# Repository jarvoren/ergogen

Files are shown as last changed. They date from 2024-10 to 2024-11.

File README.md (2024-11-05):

Monster keybord.
Pcb mounted switches and overall very basic version of the keyboard.
Ergogen used in the build in repo. Actually had a lot of problems with this one.

Will improve when i regain the will to live after this one.

Zmk firmware : 
https://github.com/jarvoren/zmk-config-monster

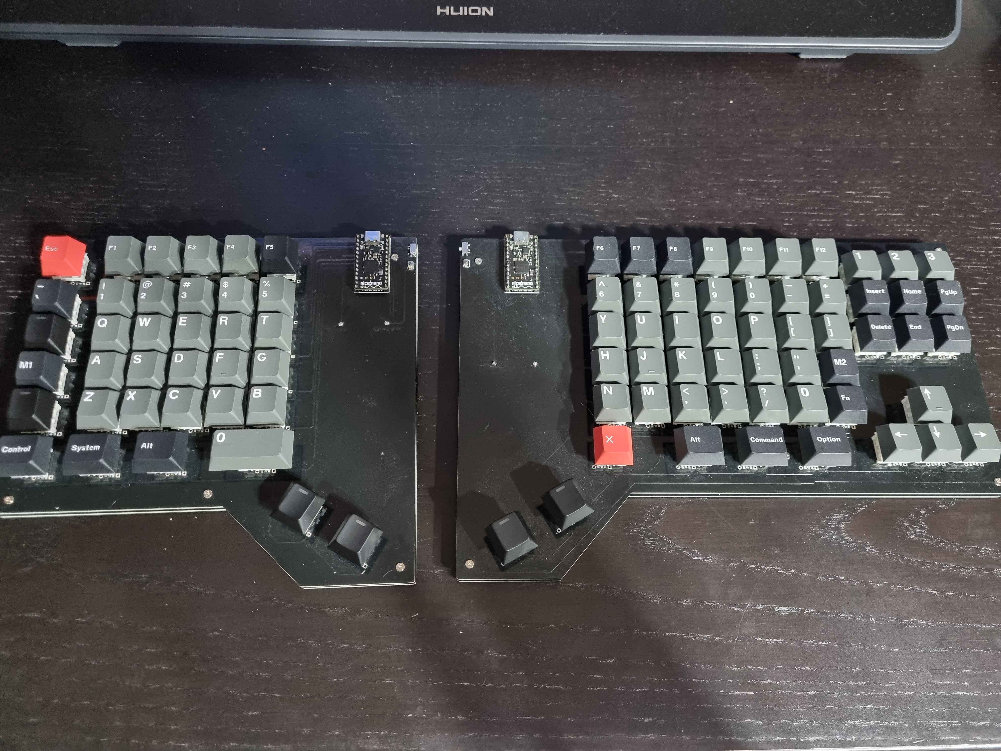
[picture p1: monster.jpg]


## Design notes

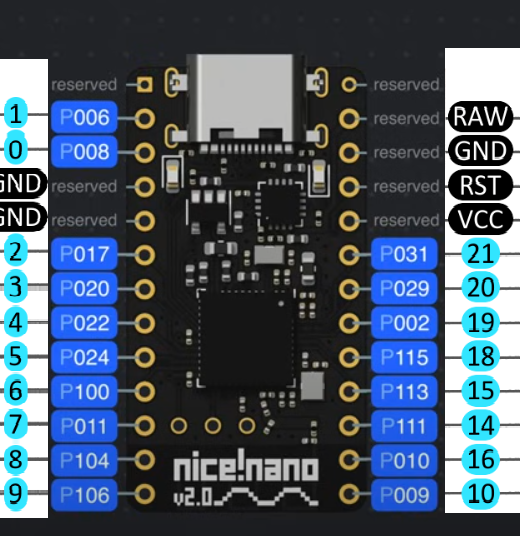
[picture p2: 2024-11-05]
configs/nicenano pinouts.png

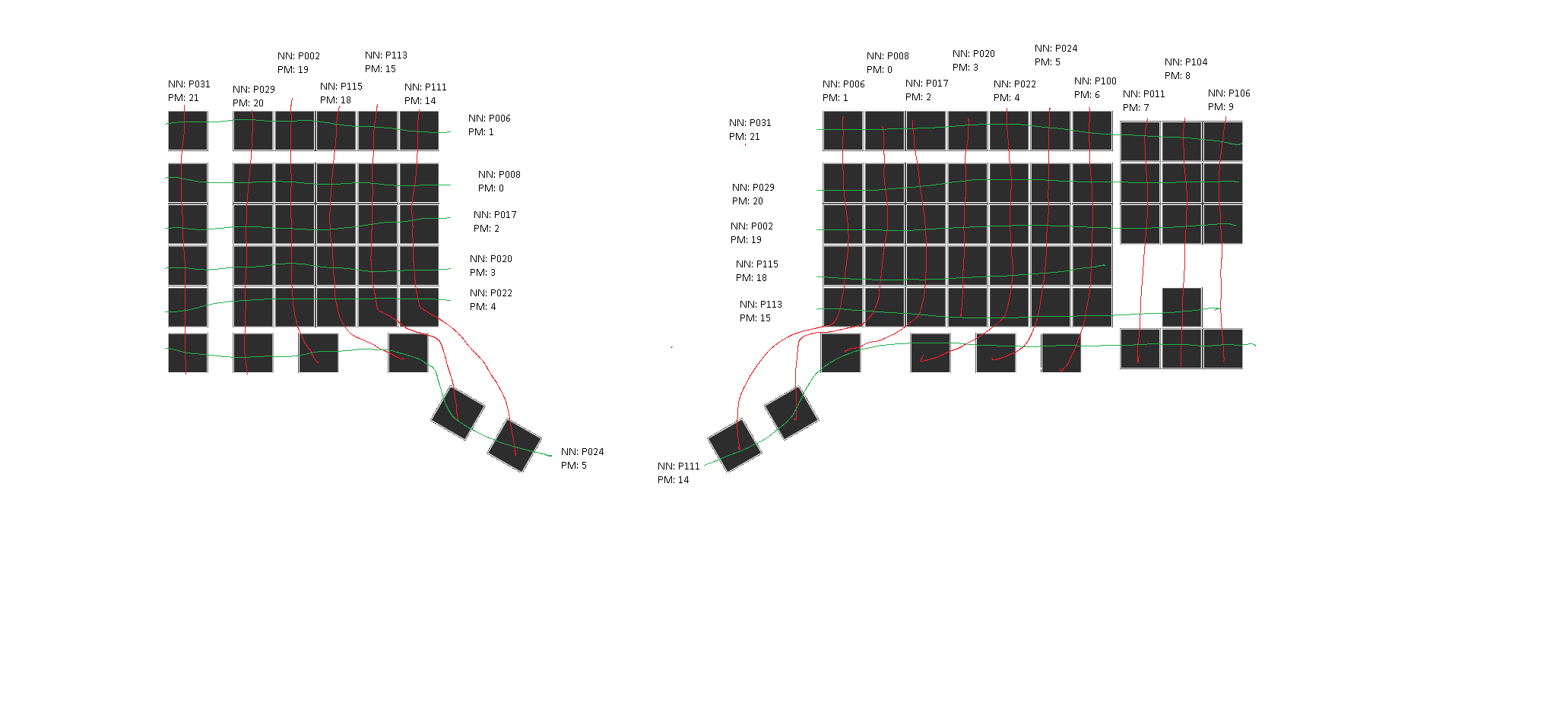
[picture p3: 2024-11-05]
configs/nicenano matrix mappings.png

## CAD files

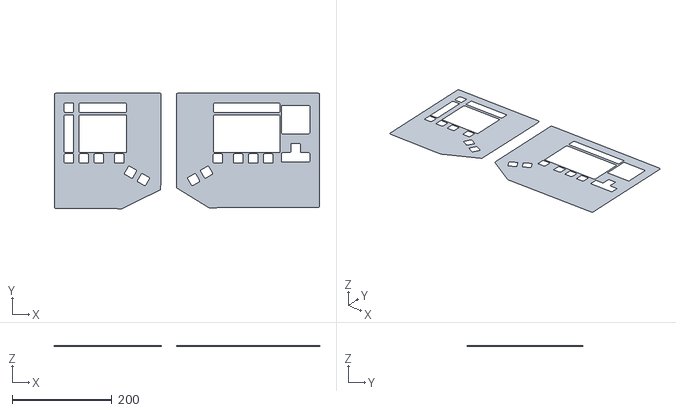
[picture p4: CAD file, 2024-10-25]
output/cases/bottom.stl
532.0 x 232.0 x 1.00

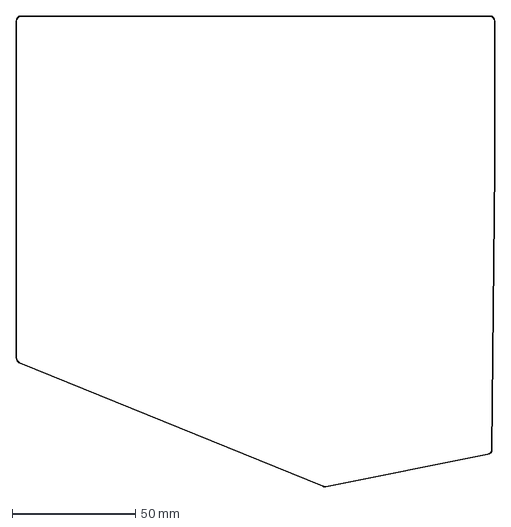
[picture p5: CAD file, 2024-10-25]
output/outlines/pcbplanleft.dxf
194.0 x 191.0 mm

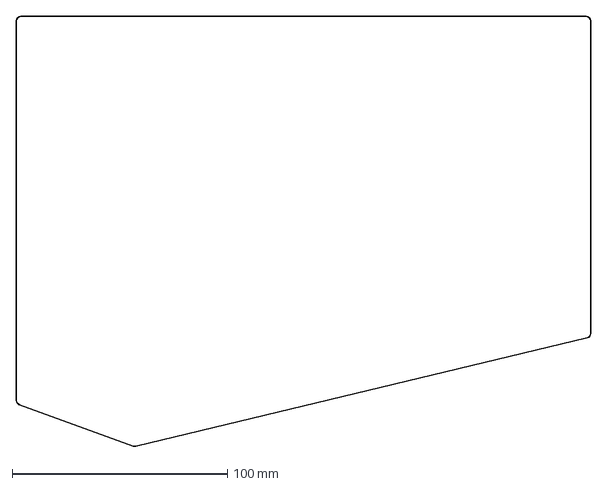
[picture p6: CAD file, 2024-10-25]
output/outlines/pcbplanright.dxf
267.0 x 200.0 mm

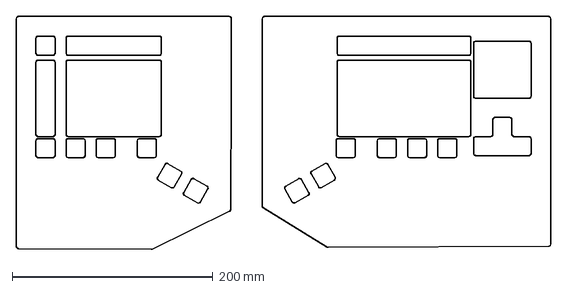
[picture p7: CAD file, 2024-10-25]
output/outlines/raw.dxf
532.0 x 232.0 mm

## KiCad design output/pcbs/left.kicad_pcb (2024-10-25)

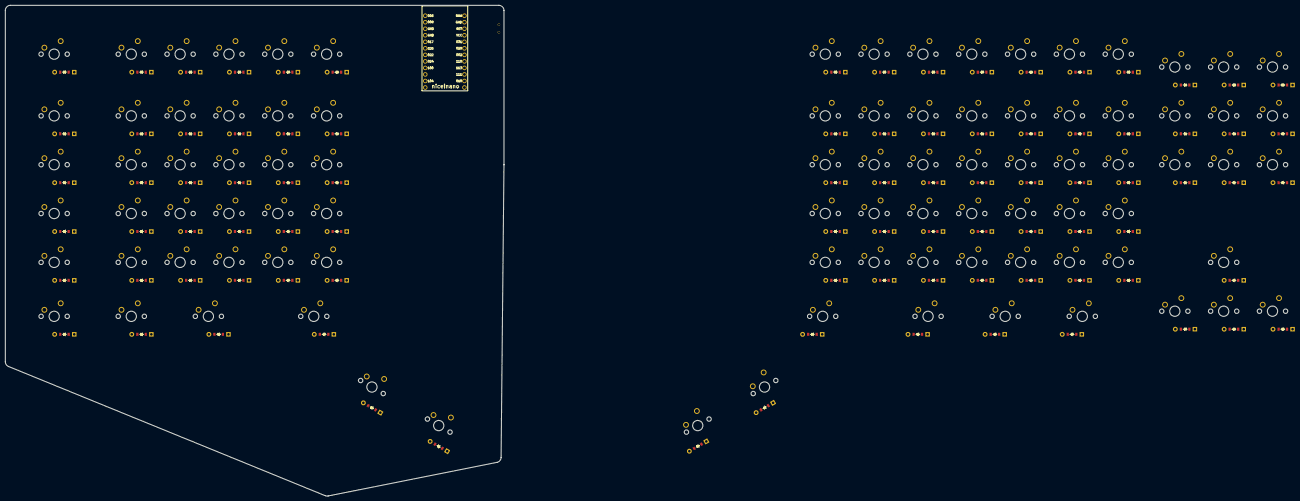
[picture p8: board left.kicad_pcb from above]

Board: 2 copper layers, 194.0 x 190.9 mm, 183 parts (0 on the bottom side), 109 nets, no tracks yet.

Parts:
B1: SW_TACT_ALPS_SKQGABE010
D1, D2, D3, D4, D5, D6, D7, D8, D9, D10, D11, D12, D13, D14, D15, D16, D17, D18, D19, D20, D21, D22, D23, D24, D25, D26, D27, D28, D29, D30, D31, D32, D33, D34, D35, D36, D37, D38, D39, D40, D41, D42, D43, D44, D45, D46, D47, D48, D49, D50, D51, D52, D53, D54, D55, D56, D57, D58, D59, D60, D61, D62, D63, D64, D65, D66, D67, D68, D69, D70, D71, D72, D73, D74, D75, D76, D77, D78, D79, D80, D81, D82, D83, D84, D85, D86, D87, D88, D89, D90: ComboDiode
MCU1: nice_nano
S1, S2, S3, S4, S5, S6, S7, S8, S9, S10, S11, S12, S13, S14, S15, S16, S17, S18, S19, S20, S21, S22, S23, S24, S25, S26, S27, S28, S29, S30, S31, S32, S33, S34, S35, S36, S37, S38, S39, S40, S41, S42, S43, S44, S45, S46, S47, S48, S49, S50, S51, S52, S53, S54, S55, S56, S57, S58, S59, S60, S61, S62, S63, S64, S65, S66, S67, S68, S69, S70, S71, S72, S73, S74, S75, S76, S77, S78, S79, S80, S81, S82, S83, S84, S85, S86, S87, S88, S89, S90: MX
T1: SPDT_C128955

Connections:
1qazcol_asdrow: D2.2, S2.2
1qazcol_numberrow: D4.2, S4.2
1qazcol_qwerow: D3.2, S3.2
1qazcol_zxcrow: D1.2, S1.2
2wsxcol_asdrow: D6.2, S6.2
2wsxcol_numberrow: D8.2, S8.2
2wsxcol_qwerow: D7.2, S7.2
2wsxcol_zxcrow: D5.2, S5.2
3edccol_asdrow: D10.2, S10.2
3edccol_numberrow: D12.2, S12.2
3edccol_qwerow: D11.2, S11.2
3edccol_zxcrow: D9.2, S9.2
4rfvcol_asdrow: D14.2, S14.2
4rfvcol_numberrow: D16.2, S16.2
4rfvcol_qwerow: D15.2, S15.2
4rfvcol_zxcrow: D13.2, S13.2
5tgbcol_asdrow: D18.2, S18.2
5tgbcol_numberrow: D20.2, S20.2
5tgbcol_qwerow: D19.2, S19.2
5tgbcol_zxcrow: D17.2, S17.2
GND: B1.1, MCU1.3, MCU1.4, MCU1.23
P002: D27.1, D31.1, D35.1, D39.1, D43.1, D47.1, D51.1, D73.1, D78.1, D82.1, MCU1.18, S5.1, S6.1, S7.1, S8.1, S55.1
P006: D53.1, D54.1, D55.1, D56.1, D57.1, D58.1, MCU1.1, S25.1, S26.1, S27.1, S28.1, S65.1
P008: D4.1, D8.1, D12.1, D16.1, D20.1, D24.1, MCU1.2, S29.1, S30.1, S31.1, S32.1, S66.1
P011: MCU1.10, S72.1, S73.1, S74.1, S75.1
P017: D3.1, D7.1, D11.1, D15.1, D19.1, D23.1, MCU1.5, S33.1, S34.1, S35.1, S36.1, S67.1
P020: D2.1, D6.1, D10.1, D14.1, D18.1, D22.1, MCU1.6, S37.1, S38.1, S39.1, S40.1, S68.1
P022: D1.1, D5.1, D9.1, D13.1, D17.1, D21.1, MCU1.7, S41.1, S42.1, S43.1, S44.1, S69.1
P024: D59.1, D60.1, D61.1, D62.1, D63.1, D64.1, MCU1.8, S45.1, S46.1, S47.1, S48.1, S70.1
P029: D28.1, D32.1, D36.1, D40.1, D44.1, D48.1, D52.1, D74.1, D79.1, D83.1, MCU1.19, S1.1, S2.1, S3.1, S4.1, S54.1
P031: D65.1, D66.1, D67.1, D68.1, D69.1, D70.1, D71.1, D75.1, D80.1, D84.1, MCU1.20, S21.1, S22.1, S23.1, S24.1, S53.1, S59.1
P100: MCU1.9, S49.1, S50.1, S51.1, S52.1, S71.1, S85.1
P104: MCU1.11, S76.1, S77.1, S78.1, S79.1, S80.1
P106: MCU1.12, S81.1, S82.1, S83.1, S84.1
P111: D72.1, D76.1, D81.1, D85.1, D86.1, D87.1, D88.1, D89.1, D90.1, MCU1.15, S17.1, S18.1, S19.1, S20.1, S58.1
P113: D25.1, D29.1, D33.1, D37.1, D41.1, D45.1, D49.1, D77.1, MCU1.16, S13.1, S14.1, S15.1, S16.1, S57.1
P115: D26.1, D30.1, D34.1, D38.1, D42.1, D46.1, D50.1, MCU1.17, S9.1, S10.1, S11.1, S12.1, S56.1
RAW: MCU1.24, T1.2
RST: B1.2, MCU1.22
alt_thumbrow: D61.2, S61.2
ctrl2_thumbrow: D63.2, S63.2
ctrl_thumbrow: D59.2, S59.2
esc_escaperow: D53.2, S53.2
f1_escaperow: D54.2, S54.2
f2_escaperow: D55.2, S55.2
f3_escaperow: D56.2, S56.2
f4_escaperow: D57.2, S57.2
f5_escaperow: D58.2, S58.2
f6_one: D65.2, S65.2
f7_one: D66.2, S66.2
f8_one: D67.2, S67.2
f9_one: D68.2, S68.2
f10_one: D69.2, S69.2
f11_one: D70.2, S70.2
f12_one: D71.2, S71.2
ikcol_hjkrow: D34.2, S34.2
ikcol_nmrow: D33.2, S33.2
ikcol_numberrow: D36.2, S36.2
ikcol_yuirow: D35.2, S35.2
left_del: D73.2, S73.2
left_down: D72.2, S72.2
left_ins: D74.2, S74.2
left_macro: D75.2, S75.2
minuscol_hjkrow: D46.2, S46.2
minuscol_nmrow: D45.2, S45.2
minuscol_numberrow: D48.2, S48.2
minuscol_yuirow: D47.2, S47.2
mirror_alt_thumbrow: D87.2, S87.2
mirror_ctrl2_thumbrow: D89.2, S89.2
mirror_ctrl_thumbrow: D85.2, S85.2
mirror_space_thumbrow: D88.2, S88.2
mirror_thumbkey_thumbrow: D90.2, S90.2
mirror_winkey_thumbrow: D86.2, S86.2
olcol_hjkrow: D38.2, S38.2
olcol_nmrow: D37.2, S37.2
olcol_numberrow: D40.2, S40.2
olcol_yuirow: D39.2, S39.2
pcol_hjkrow: D42.2, S42.2
pcol_nmrow: D41.2, S41.2
pcol_numberrow: D44.2, S44.2
pcol_yuirow: D43.2, S43.2
pluscol_hjkrow: D50.2, S50.2
pluscol_nmrow: D49.2, S49.2
pluscol_numberrow: D52.2, S52.2
pluscol_yuirow: D51.2, S51.2
right_del: D82.2, S82.2
right_down: D81.2, S81.2
right_ins: D83.2, S83.2
right_macro: D84.2, S84.2
space_thumbrow: D62.2, S62.2
tabcapsshift_caps: D23.2, S23.2
tabcapsshift_shift: D24.2, S24.2
tabcapsshift_tab: D22.2, S22.2
tabcapsshift_tylda: D21.2, S21.2
thumbkey_thumbrow: D64.2, S64.2
ujmcol_hjkrow: D30.2, S30.2
ujmcol_nmrow: D29.2, S29.2
ujmcol_numberrow: D32.2, S32.2
ujmcol_yuirow: D31.2, S31.2
updown_del: D78.2, S78.2
updown_down: D76.2, S76.2
updown_ins: D79.2, S79.2
updown_macro: D80.2, S80.2
updown_up: D77.2, S77.2
winkey_thumbrow: D60.2, S60.2
yhncol_hjkrow: D26.2, S26.2
yhncol_nmrow: D25.2, S25.2
yhncol_numberrow: D28.2, S28.2
yhncol_yuirow: D27.2, S27.2

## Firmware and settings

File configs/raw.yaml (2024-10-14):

units:
  os: 300 #opositeside
  escSpacing: 11
  keyoutlinespacing: 15
points:
  zones:
    matrixleft:
      columns:
        1qazcol:
            key:
                column_net: P029
        2wsxcol:
            key:
                column_net: P002
        3edccol:
            key:
                column_net: P115     
        4rfvcol:
            key:
                column_net: P113
        5tgbcol:
            key:
                column_net: P111
      rows:
        zxcrow:
          row_net: P022
          asym: source
        asdrow:
            row_net: P020
            asym: source
        qwerow:
            row_net: P017
            asym: source
        numberrow:
            row_net: P008
            asym: source
    EscTabCapsShiftColumn:
      anchor:
        ref: matrixleft_1qazcol_zxcrow
        shift: [-30,0]
      columns:
        tabcapsshift:
            key:
                column_net: P031
      rows:
        tylda:
            row_net: P022
            asym: source
        tab:
            row_net: P020
            asym: source
        caps:
            row_net: P017
            asym: source
        shift:
            row_net: P008
            asym: source
    matrixright:
      anchor:
        ref: EscTabCapsShiftColumn_tabcapsshift_tylda
        shift: [os,0]
      columns:
        yhncol:
            key:
                column_net: P006
        ujmcol:
            key:
                column_net: P008
        ikcol:
            key:
                column_net: P017
        olcol:
           key:
                column_net: P020
        pcol:
            key:
                column_net: P022
        minuscol:
            key:
                column_net: P024
        pluscol:
            key:
                column_net: P100
      rows:
        nmrow:
            row_net: P113
            asym: source
        hjkrow:
            row_net: P115
            asym: source
        yuirow:
            row_net: P002
            asym: source
        numberrow:
            row_net: P029
            asym: source
    functionKeysleft:
      anchor:
        ref: EscTabCapsShiftColumn_tabcapsshift_shift
        shift: [0,24]
      columns:
        esc:
            key.column_net: P031
        f1:
            key.column_net: P029
            key.shift: [escSpacing]
        f2:
            key.column_net: P002
            key.shift: [escSpacing]
        f3:
            key.column_net: P115
            key.shift: [escSpacing]
        f4:
            key.column_net: P113
            key.shift: [escSpacing]
        f5:
            key.column_net: P111
            key.shift: [escSpacing]
      rows:
        escaperow:
            row_net: P006
            asym: source
################################################################################
################################################################################
#THUMB KEYS FOR LEFT SIDE MAPPING
################################################################################        
    ThumbKeys:
        anchor:
            ref: EscTabCapsShiftColumn_tabcapsshift_tylda
            shift: [0,-21]
        columns:
            ctrl:
                key.column_net: P031
                key.mirror.column_net: P100
            winkey:
                key.column_net: P029
                key.mirror.column_net: P024
                key:
                    #width: 1.5*u
                    shift: [escSpacing]
            alt:
                key.column_net: P002
                key.mirror.column_net: P022
                key:
                #width: 1.5*u
                    shift: [escSpacing+escSpacing]
            space:
                key.column_net: P115
                key.mirror.column_net: P017
                key:
                    shift: [escSpacing+3*escSpacing]
            ctrl2:
                key.column_net: P113
                key.mirror.column_net: P008
                key:
                    splay: -30
                    shift: [escSpacing+4*escSpacing]
            thumbkey:
                key.column_net: P111
                key.mirror.column_net: P006
                key:
                    shift: [escSpacing+5*escSpacing]
        rows:
            thumbrow:
                row_net: P024
                mirror.row_net: P111
################################################################################
################################################################################
#THUMB KEYS FOR MIRROR MAPPING UNCOMMENT PROPER ONE
################################################################################
#    ThumbKeys:
#      anchor:
#        ref: EscTabCapsShiftColumn_tabcapsshift_tylda
#        shift: [0,-21]
#      columns:
#        ctrl:
#            key.column_net: P100
#        winkey:
#            key.column_net: P024
#            key:
#                #width: 1.5*u
#                shift: [escSpacing]
#        alt:
#            key.column_net: P022
#            key:
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

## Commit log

2024-10-05 move folders around and initial keyboard plan
    Move folders and create initial keyboard plan
    [_export.dxf, _export.kicad_pcb, adjustments___demo_dxf.dxf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]
2024-10-06 pcb: include nano micro comunity file and fix generation
    [Keyboard.kicad_pcb, Keyboard.kicad_sch, left.kicad_pcb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]
2024-10-10 wip: add pcbs and wireing scheme
2024-10-11 leftpcb: finished wireing left pcb
    Moving on from ergogen to kicad. Add wireing for pcb and moving pcb to
    finished folder.
    [Keyboard.kicad_pcb, Keyboard.kicad_sch, left.kicad_pcb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]
2024-10-14 folder cleanup and wired pcbs upload
    [finishedleftpcb-B_Cu.gbr, finishedleftpcb-B_Mask.gbr, finishedleftpcb-B_Paste.gbr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]
2024-10-25 finalize v1
    Final version of monster keyboard pcb. Ergogen generated files needed
    touchups. Stl files need work - currently dropped from v1.
    [backup left-B_Cu.gbr, backup left-B_Mask.gbr, backup left-B_Paste.gbr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]
2024-11-05 fix drawings for connectors
